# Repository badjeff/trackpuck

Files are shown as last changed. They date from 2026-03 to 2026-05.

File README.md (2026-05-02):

# Trackpuck

6 DoF input peripheral designed for CAD.

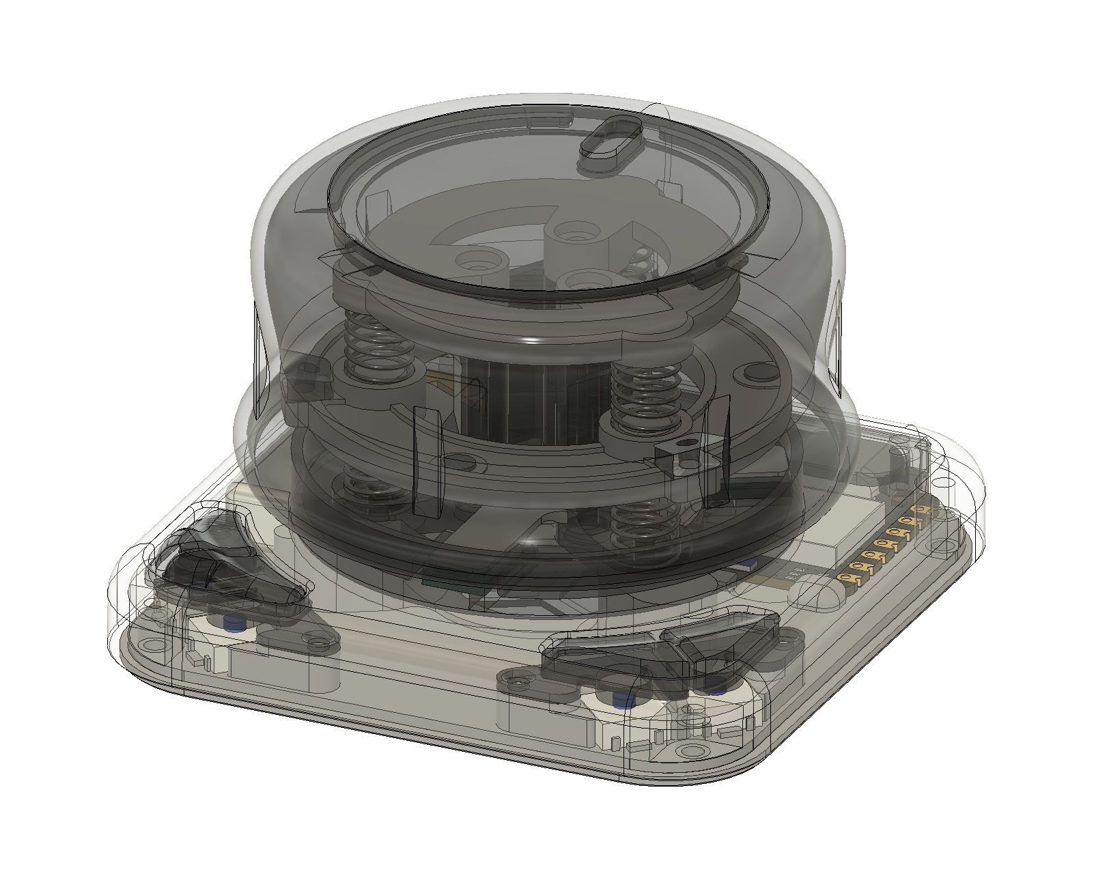
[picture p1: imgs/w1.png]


### Design Principles
- 6DoF tracking output as HID Joystick
- Integrated magnetometers [mlx90393-pcb](https://github.com/badjeff/mlx90393-pcb)
- Do **NOT** spoof to be one specific peripheral and complies with the software terms and conditions of other vendors
- Powered by [ZMK](https://github.com/zmkfirmware/zmk) => OSS, on-devie profiling, say no to vendor lock eco-system
- Compatible for seeed xiao ble form factor mcu board
- 3D printed go-first
- Wireless (but, magnetometer are not quite power efficient ATM)
- Lightness (referring to weight and control)
- Medium to small size
- Rigid
- Low Profile

### Gallery

<p float="left">
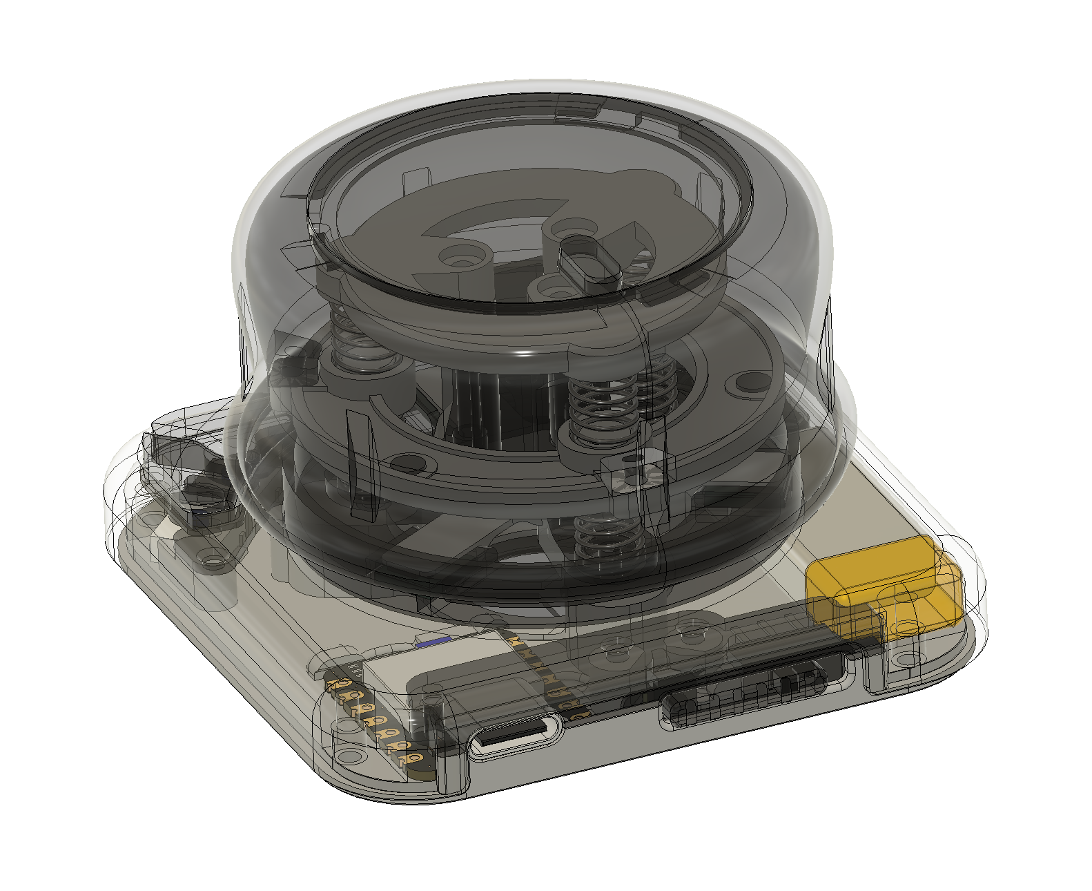
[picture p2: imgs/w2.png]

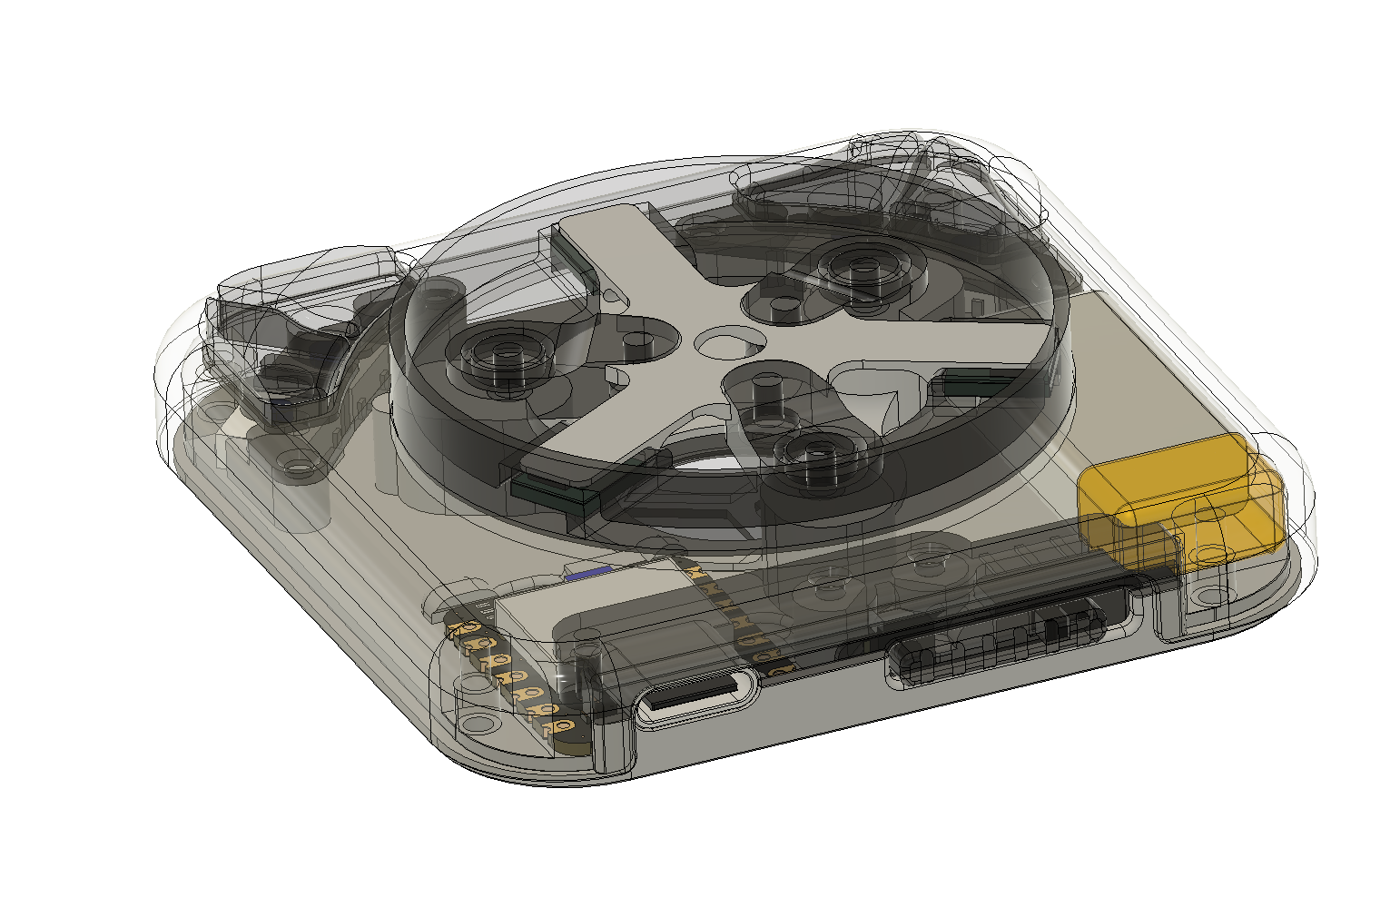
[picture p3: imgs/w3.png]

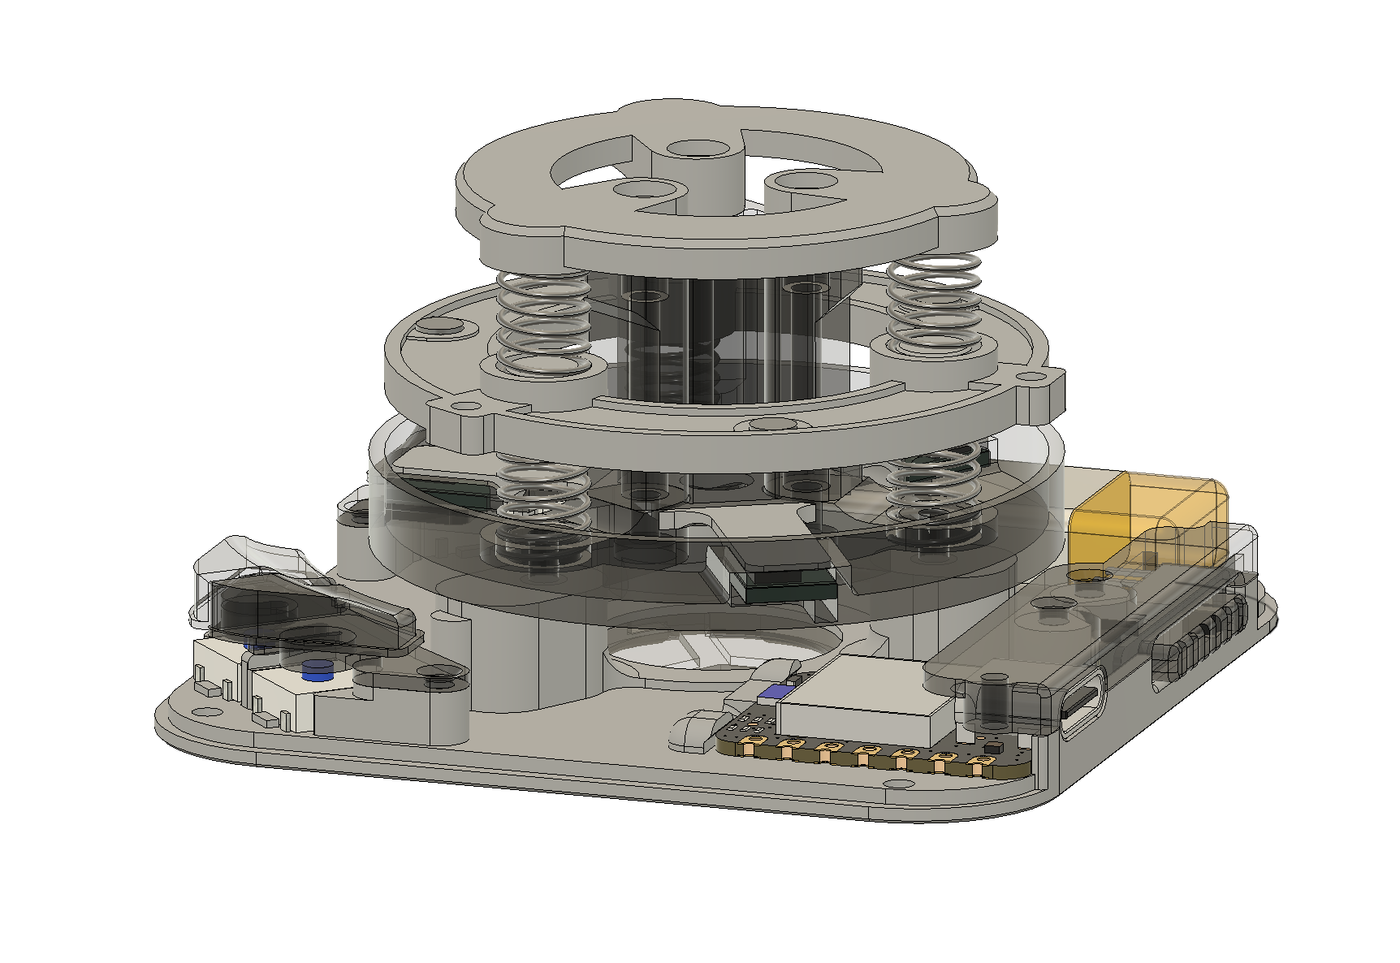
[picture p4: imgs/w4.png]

</p>

<p float="left">
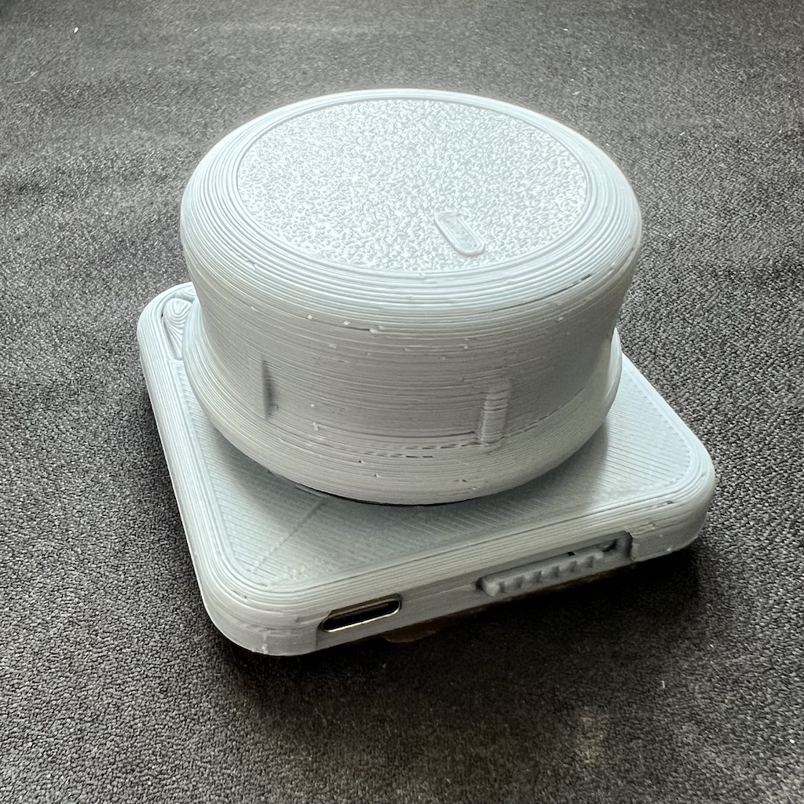
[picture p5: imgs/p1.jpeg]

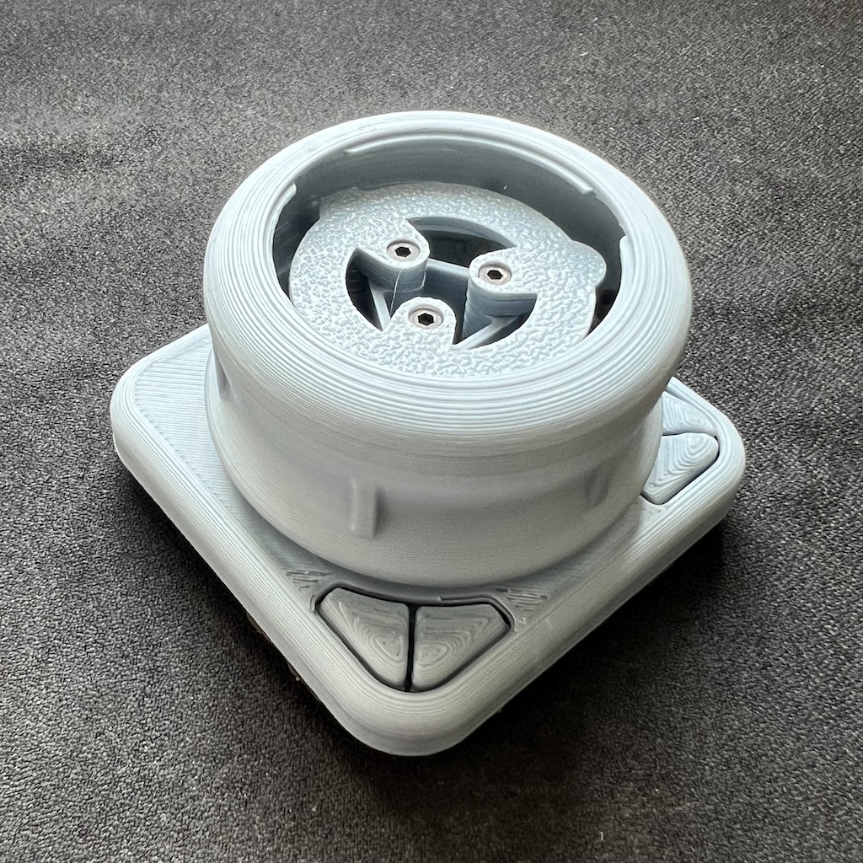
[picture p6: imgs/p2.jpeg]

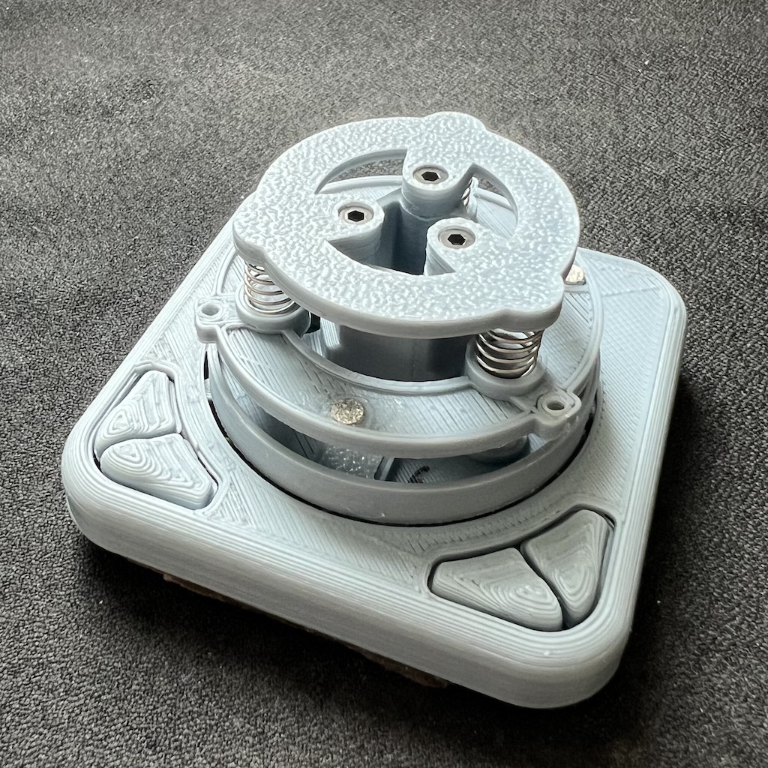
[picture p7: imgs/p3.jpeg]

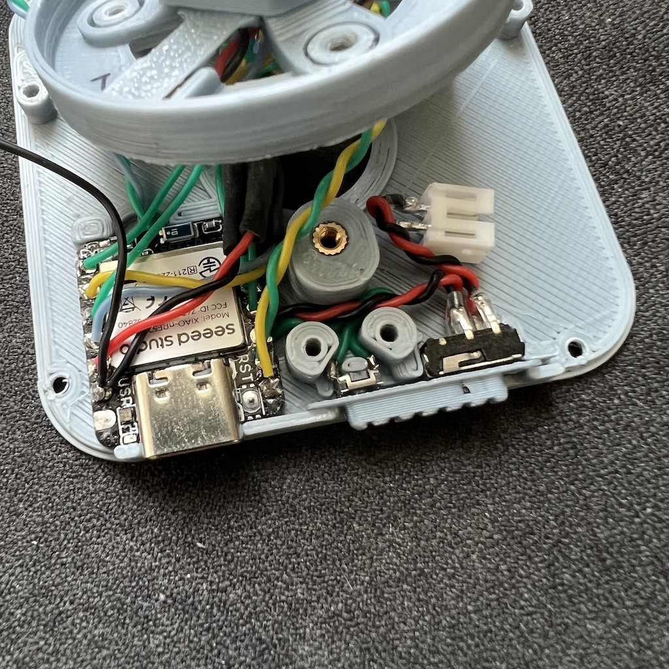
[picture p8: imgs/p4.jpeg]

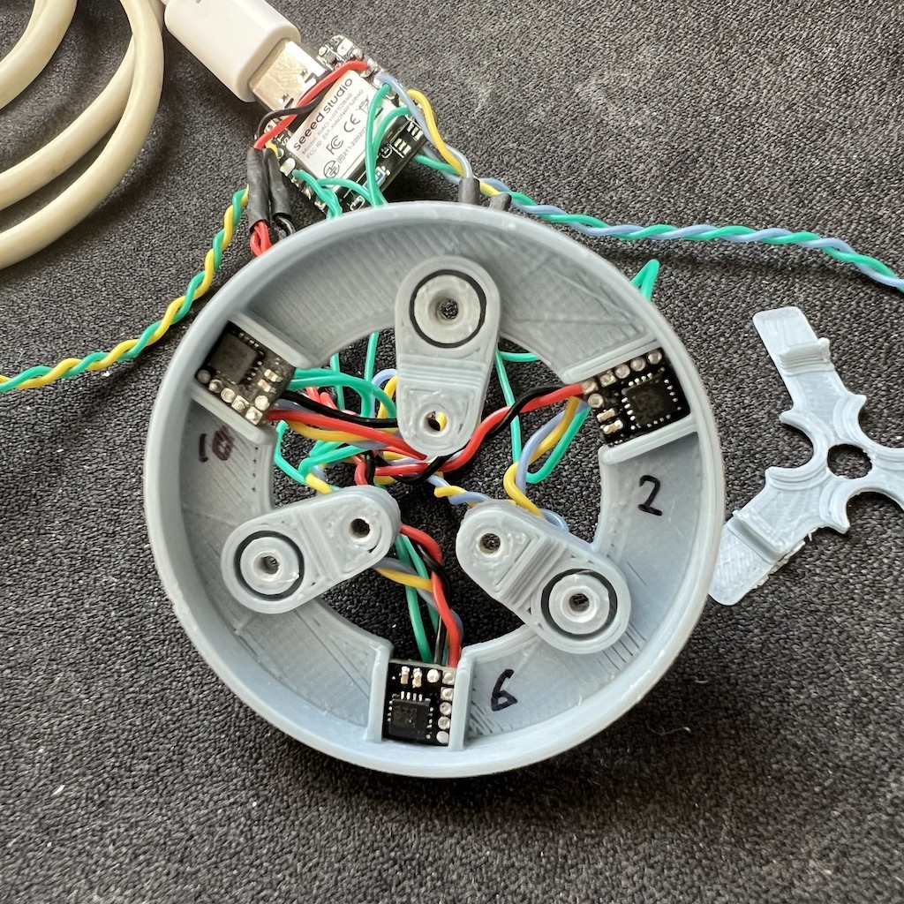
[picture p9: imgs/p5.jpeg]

</p>

https://github.com/user-attachments/assets/f231d02b-527b-4762-a200-921404486fa5

*Video 1: Navigating in Fusion 360 with TrackpuckTools Add-ins

https://github.com/user-attachments/assets/83aaf9c9-1d84-4c99-927c-6f882763e450

*Video 2: Navigating in Blender 4.5 with TrackpuckTools Extension Scripts

### BOM
|Unit|Item|
|-|-|
|1|Seeed Studio XIAO BLE (nRF52840)|
|3|MLX90393SLW Sensor [Breakout](https://github.com/badjeff/mlx90393-pcb)|
|3|3mm x 1mm (Diameter x Height) Neodymium Magnets|
|4|ALPS SKRAAWE010 Micro Switch|
|1|MSK-1153 6 Pins Power Switch|
|1|3x4x2mm Tact Switch Turtle Switch|
|1|601230 Lipo Battery (plus connector)|
|6|6mm x 12mm x 4.7mm Springs|
|10|M2 Threaded Heat Set Inserts 3mm x 3mm (Diameter x Height) |
|6|10mm M2 Sunk Head Screws |
|6|4mm M2 Sunk Head Screws|
|4|3mm M2 Sunk Head Screws|
|1|28/26 AWG silicone wire|

### Building Guide / Tips

- NOT for beginner. Requiring experience of building at least one wireless keyboard on [ZMK](https://github.com/zmkfirmware/zmk).
- MUST have a funcation brain. Requiring to puzzling to assemble all parts together.
- NEED very good eyesight, and soldering skill (and tools).
- Build the core tower first.
- Sensor breakouts order is counter clockwise started from 6 o'clock position
- This peripheral doesn't required the weights. Use reusable self-adhesive sticky silicone gel pads from [Amazon](https://www.amazon.co.uk/silicone-Anti-Slip-holders-washable-transparent/dp/B07CGRHT31).
- Tell AI agent read [zmk,input-processor-trixer](https://github.com/badjeff/trackpuck-zmk-config/blob/main/boards/shields/trackpuck/input_processor_trixer.c) before you prompt it to adjust the rates for you. But, you still can find each config description in .yml file before messing up the default rates.

### Firmware

The ZMK firmware config repository can be find at [HERE](https://github.com/badjeff/trackpuck-zmk-config).

The peripheral will present itself as a mixture of keyboard and joystick with ZMK module [zmk-hid-joystick](https://github.com/badjeff/zmk-hid-joystick). The sensors are handled by ZMK module [zmk-mlx90393-driver](https://github.com/badjeff/zmk-mlx90393-driver). 3D space convertion is handled in an embedded input-processor [zmk,input-processor-trixer](https://github.com/badjeff/trackpuck-zmk-config/blob/main/boards/shields/trackpuck/input_processor_trixer.c) in firmware config repo.

### Related Projects

- [TrackpuckTools-Fusion360](https://github.com/badjeff/TrackpuckTools-Fusion360) is a Fusion 360 add-in that connects HID-based 6DoF input peripheral devices as navigation input for Fusion 360, providing fluid control over camera orbit, pan, zoom, and rotation.

- [TrackpuckTools-Blender](https://github.com/badjeff/TrackpuckTools-Blender) is a Blender add-in that connects HID-based 6DoF input peripheral devices as navigation input for Fusion 360, providing fluid control over camera orbit, pan, zoom, and rotation.

- [Magnetometers tracking simulator web app](https://sim7dof4ve.vercel.app/) will show how this all thigs works.

- [A example web app](https://trackpuck-threejs-examples.vercel.app/). Used to test HID Joystick outputs via web gamepad api.

## License

This work is licensed under a Creative Commons Attribution-NonCommercial-ShareAlike 4.0 International License. (CC BY-NC-SA 4.0)

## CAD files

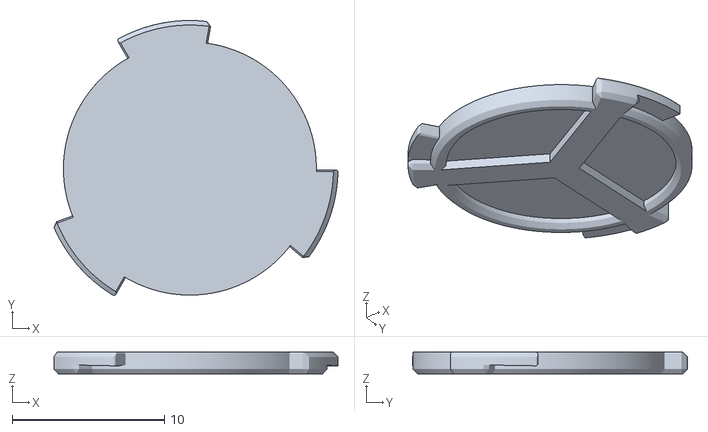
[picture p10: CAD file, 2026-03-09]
STLs/base lid.stl
18.6 x 18.0 x 1.42

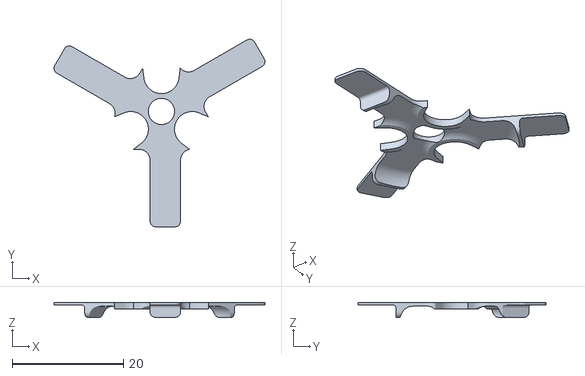
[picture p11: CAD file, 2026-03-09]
STLs/pcb clip.stl
38.0 x 33.7 x 2.65

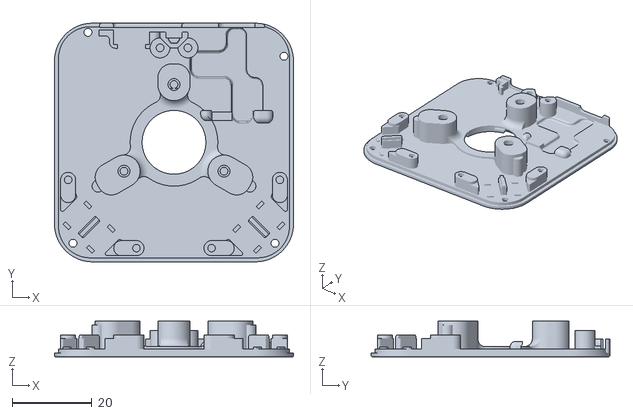
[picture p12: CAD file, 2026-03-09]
STLs/base.stl
60.0 x 59.9 x 8.99

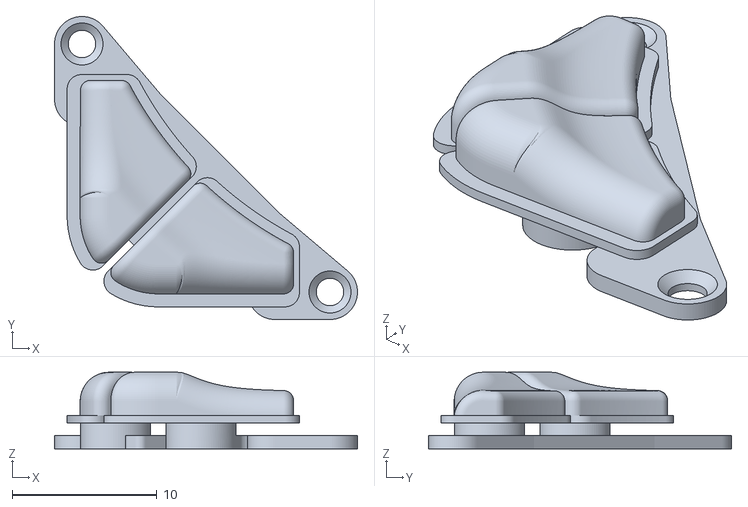
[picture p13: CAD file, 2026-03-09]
STLs/cap.stl
20.9 x 20.9 x 5.29

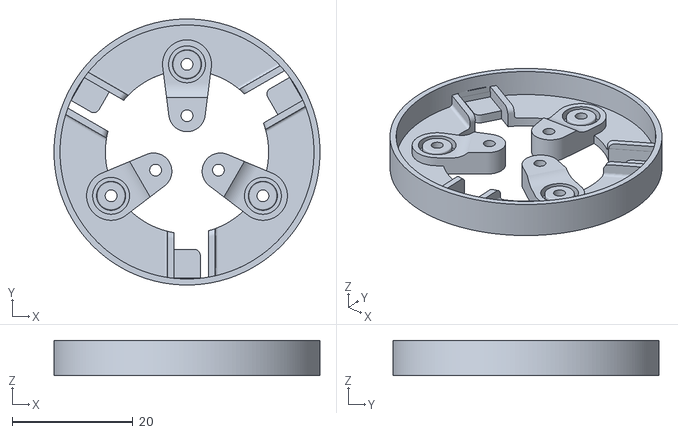
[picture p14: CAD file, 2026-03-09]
STLs/core btm.stl
44.0 x 44.0 x 5.80

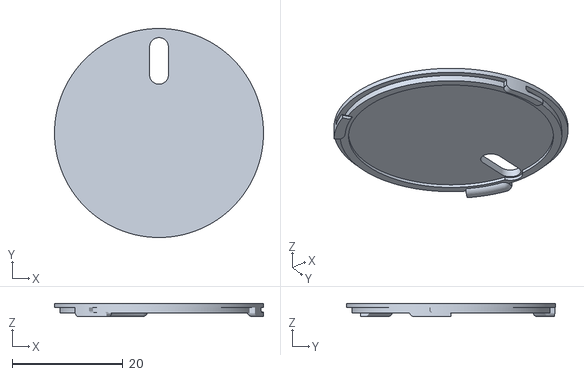
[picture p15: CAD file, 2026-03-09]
STLs/puck lid.stl
37.7 x 37.7 x 2.40

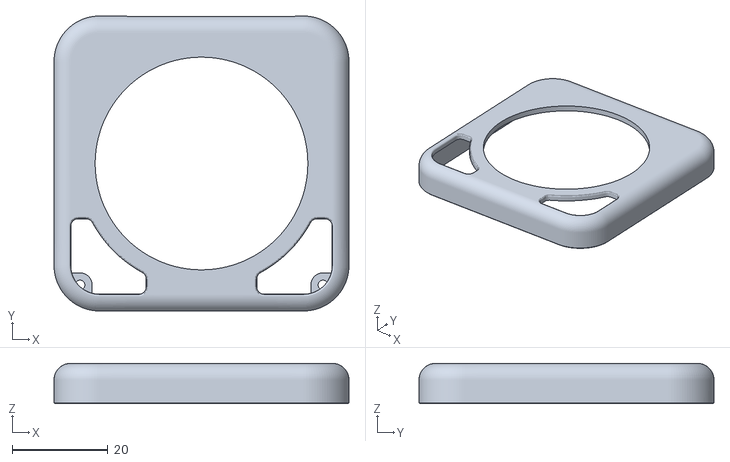
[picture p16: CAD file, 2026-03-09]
STLs/case.stl
61.6 x 61.6 x 8.45

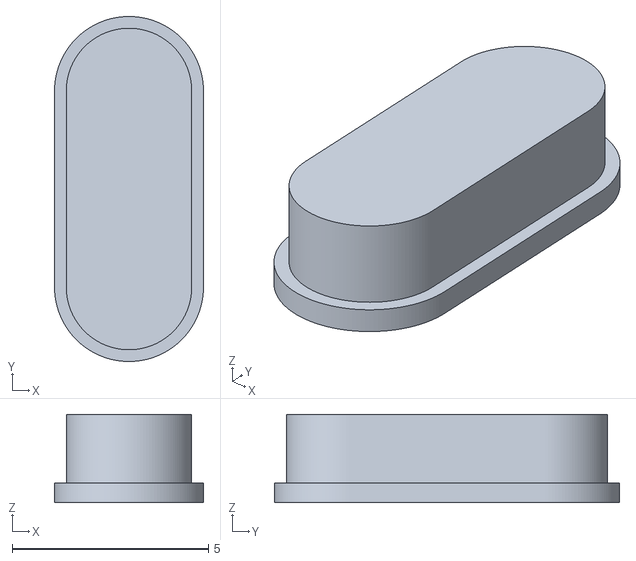
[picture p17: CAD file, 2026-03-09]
STLs/puck lid slot.stl
3.80 x 8.80 x 2.25

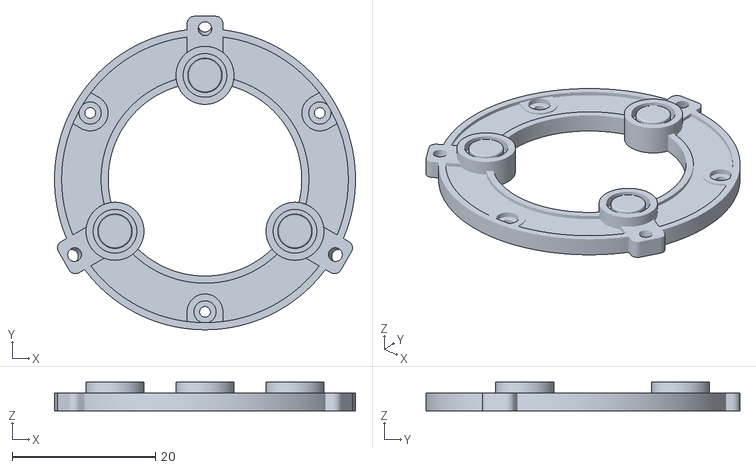
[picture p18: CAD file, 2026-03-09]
STLs/core mid.stl
42.0 x 43.7 x 4.00

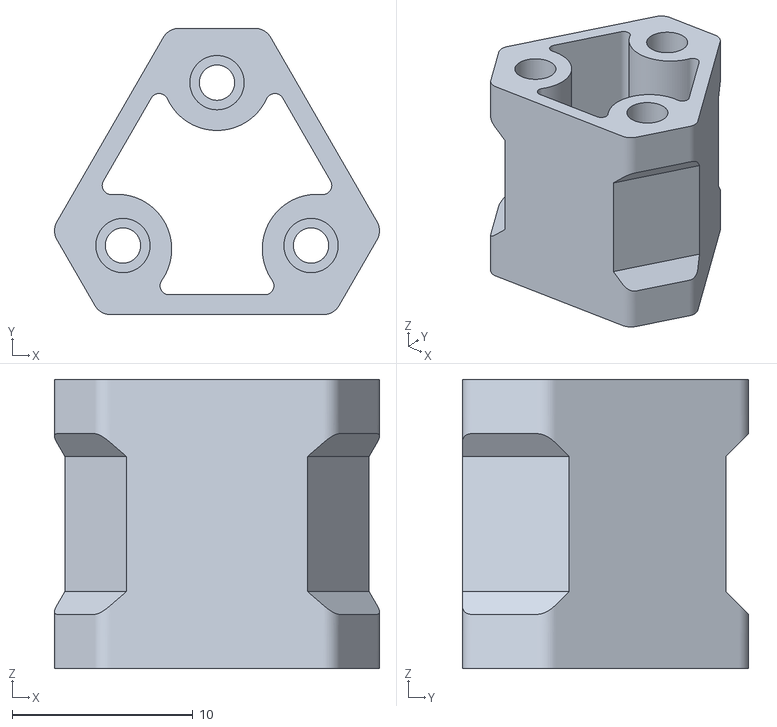
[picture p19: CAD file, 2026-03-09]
STLs/core stem.stl
18.0 x 15.8 x 16.0

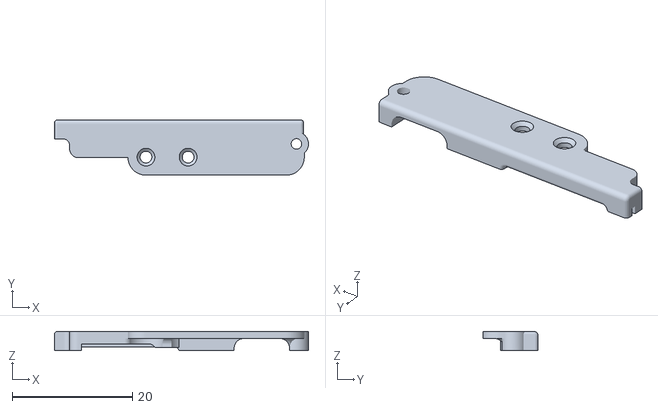
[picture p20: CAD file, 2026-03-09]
STLs/mcu clip.stl
42.2 x 9.20 x 3.21

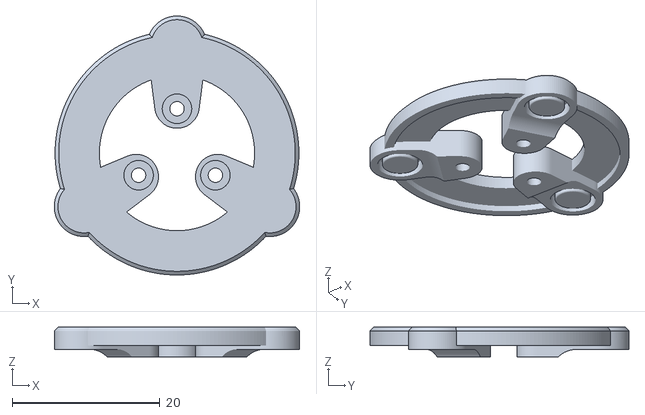
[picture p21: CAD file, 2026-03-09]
STLs/core top.stl
33.2 x 35.0 x 4.00

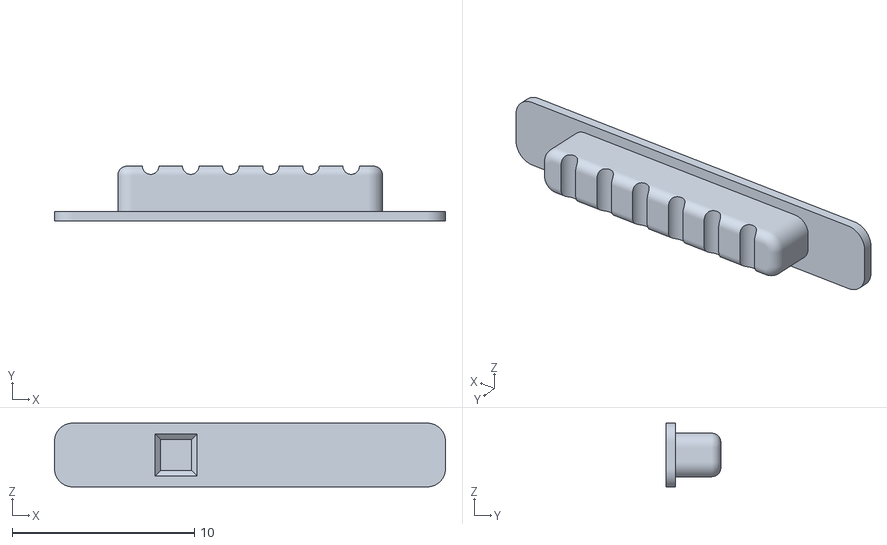
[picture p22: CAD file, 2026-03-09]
STLs/power btn.stl
21.5 x 3.00 x 3.50

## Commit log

2026-03-09 init commit
    [base lid.stl, base.stl, cap.stl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]
2026-03-10 Correct term for M2 Threaded Heat Set Inserts
